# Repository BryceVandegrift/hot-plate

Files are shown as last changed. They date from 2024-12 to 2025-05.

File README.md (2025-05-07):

# PCB Hot Plate

A modular PCB soldering hot plate using only through hole components

## About

A modular PCB hot plate designed for hot plate soldering. It is designed for SMD
soldering and can go up to 180°C. Made using only through hole components in
order to make it easy to be built by hobbyists.

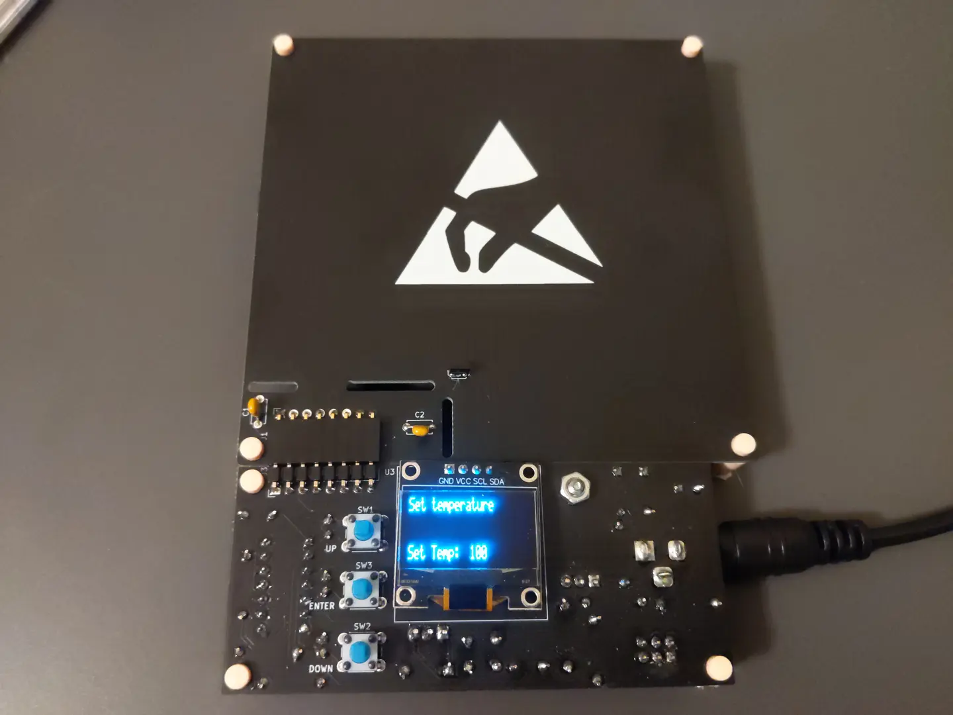
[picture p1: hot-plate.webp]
PCB Hot Plate


## Specifications

- 180°C max temperature
- Microcontroller: Atmel ATTINY84A
- Display: 128x64 pixel SSD1306 or compatible display
- Modular/interchangeable hot plates
- Support for simple heat curves
- 18-20 volt 2x5.5mm DC input
- 3 button input

Best used with low melt solder paste. This includes (but is not limited to):
- Sn48/In52
- Sn42/Bi58
- Sn42/Bi57/Ag1.0

## Usage

When you power up the hot plate you will be presented with 2 modes:

- Normal heating
- Heat curve

### Normal Heating

Normal heating mode is very simple to use. Just set a temperature and the hot
plate will heat up and stay at the set temperature. You can press `Enter` in
order to enter into cooling mode afterwards.

### Heat Curve

Heat curve mode lets you set and use your own custom heat curve. There are 5
parts to heat curve mode:

- Preheat: Temperature to preheat
- Soak: Amount of time (in seconds) to "soak" in preheat temperature
- Reflow heating: Temperature to reflow
- Reflow: Amount of time (in seconds) to reflow
- Cooldown

Pressing `Enter` will skip to the next stage of the heat curve.
Heat curve mode roughly follows this graph:

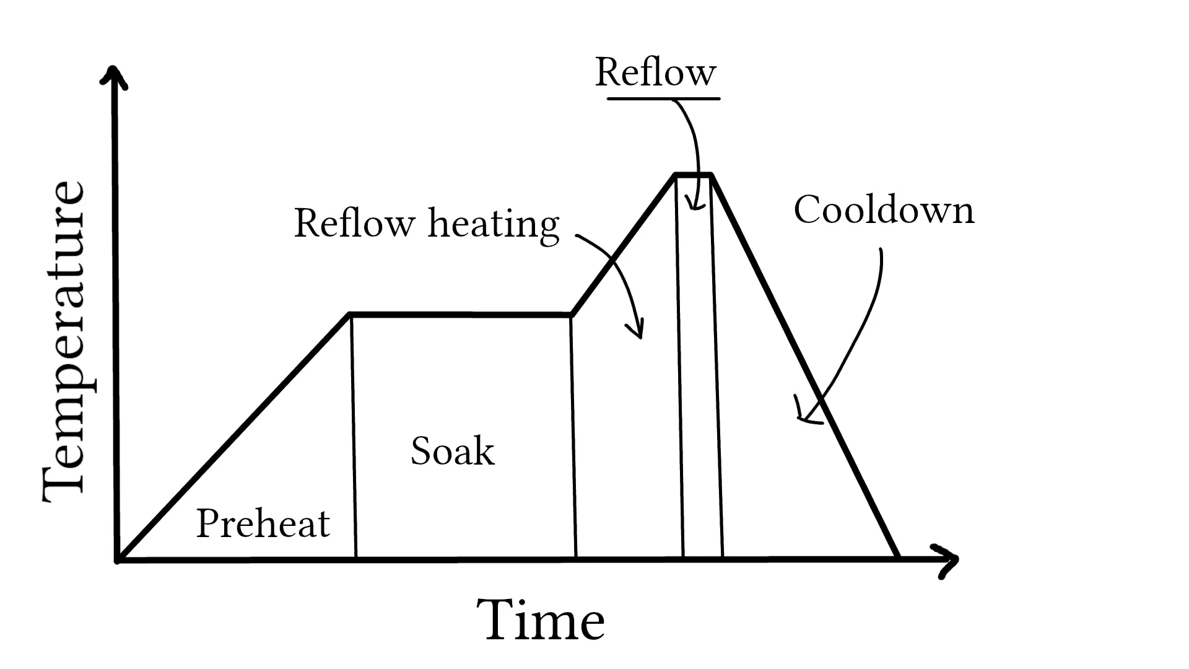
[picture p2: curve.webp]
Graph of heat curve


## Hardware

### Schematics

[Control Board Schematic](KiCAD/schematics/plate.pdf)

[Hot Plate Schematic](KiCAD/schematics/100x100-plate.pdf)

### Build Instructions

Please refer to the [Building Instructions](Build.md) page for detailed instructions.

### Connectors and Switches

#### J1 - DC Power Input

| Pin | Description |
| --- | --- |
| 1 | +18-20V power |
| 2 | Ground |
| 3 | Ground |

#### J2 - ISCP Header

| Pin | Description  |
| --- | ---  |
| 1 | MISO |
| 2 | +5V |
| 3 | SCL |
| 4 | MOSI |
| 5 | Reset |
| 6 | Ground |

#### J3 - Hot Plate Connector

| Pin | Description |
| --- | --- |
| 1 | NC |
| 2 | +18-20V |
| 3 | +18-20V |
| 4 | MOSFET drain |
| 5 | MOSFET drain |
| 6 | +5V |
| 7 | Ground |
| 8 | Temp. sensor output |

*Note: The J3 connector on the control board is exactly the same as the J1
connector on the hot plate board*

### Bill of Materials

A list of all Digikey parts can be found [here](https://www.digikey.com/en/mylists/list/93WA87OA5L)

#### Control Board

| Type | Reference | Description | Quantity | Source |
| ---- | --- | --- | --- | --- |
| Integrated Circuit | U1 | L7805CV voltage regulator | 1 | Digikey 497-1443-5-ND |
| Integrated Circuit | U2 | ATTINY84A-PU microcontroller | 1 | Digikey ATTINY84A-PU-ND |
| Display | U3 | SSD1306 128x64 0.96" display | 1 | Ebay, AliExpress, and other sources |
| IC Socket | U2 | DIP-14 300 mil socket | 1 | Digikey ED3014-ND |
| Diode | D1, D2 | SD103A | 2 | Digikey SD103AVSCT-ND |
| Diode | D3 | 1N5231 | 1 | Digikey 1N5231B-ND |
| MOSFET | Q1 | IRLZ44N | 1 | Digikey IRLZ44NPBF-ND |
| Capacitor | C1 | 100uF, Electrolytic, 3.5mm lead spacing | 1 | Digikey 732-9187-1-ND |
| Capacitor | C2-C4, C8 | 0.1uF, MLCC, 5mm lead spacing | 4 | Digikey BC2665CT-ND |
| Capacitor | C5-C7 | 3300pF, MLCC, 2.5mm lead spacing | 3 | Digikey BC1075CT-ND |
| Resistor | R1-R5, R7 | 10kOhm, through hole | 6 | Digikey 13-MFR-25FRF52-10KCT-ND |
| Resistor | R6 | 30kOhm, through hole | 1 | Digikey 13-MFR-25FTE52-30KCT-ND |
| Resistor | R8 | 200Ohm, throught hole | 1 | Digikey 200XBK-ND |
| Tactile Button | SW1-SW3 | 6mm tactile button | 3 | Digikey 450-1654-ND |
| DC Jack | J1 | 2x5.5mm, through hole, right angle | 1 | Digikey CP-002AH-ND |
| Pin Header | J2 | 6 pin header, 2.54mm pitch, 2x3 pins | 1 | Digikey 732-5394-ND |
| Pin Header | J3 | 8 pin header, 2.54mm pitch, right angle | 1 | Digikey 2057-PH1RB-08-UA-ND |

#### Hot Plate

| Type | Reference | Description | Quantity | Source |
| ---- | --- | --- | --- | --- |
| Integrated Circuit | U1 | LMT87LPGM temperature sensor | 1 | Digikey 296-LMT87LPGMCT-ND |
| Capacitor | C1, C2 | 0.1uF, MLCC, 5mm lead spacing | 2 | Digikey BC2665CT-ND |
| Pin Socket | J1 | 8 pin header, 2.54mm pitch, right angle | 1 | Digikey S5483-ND |

## License

Source code is licensed under the GPLV3 or later.

Everything else is licensed under the CERN-OHL-W-2.0.

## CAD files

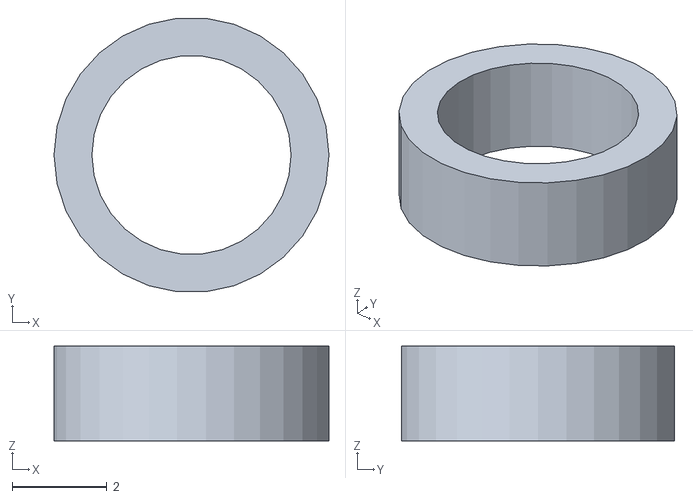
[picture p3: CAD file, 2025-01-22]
3d/ring.stl
5.80 x 5.77 x 2.00

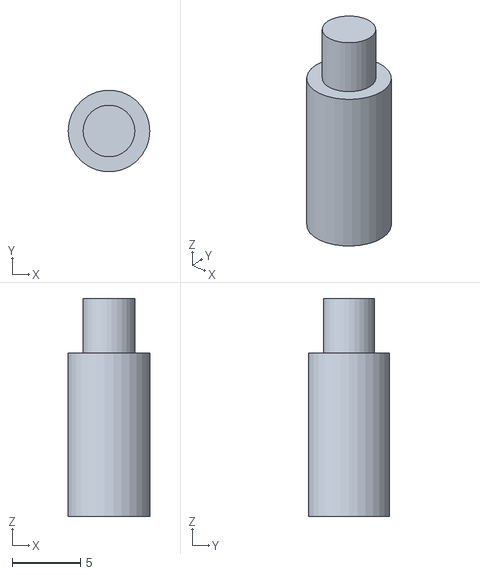
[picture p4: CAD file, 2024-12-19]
3d/peg.stl
6.00 x 5.97 x 16.0

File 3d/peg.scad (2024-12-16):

/* See LICENSE for license details. */

$fn = 30;

cylinder(h = 12, d = 6);
translate([0, 0, 12]) {
    cylinder(h = 4, d = 3.8);
}

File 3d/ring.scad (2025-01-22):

$fn = 30;

difference() {
    cylinder(h = 2, d = 5.8);
    translate([0, 0, -0.5]) {
        cylinder(h = 3, d = 3.8 + 0.4);
    }
}

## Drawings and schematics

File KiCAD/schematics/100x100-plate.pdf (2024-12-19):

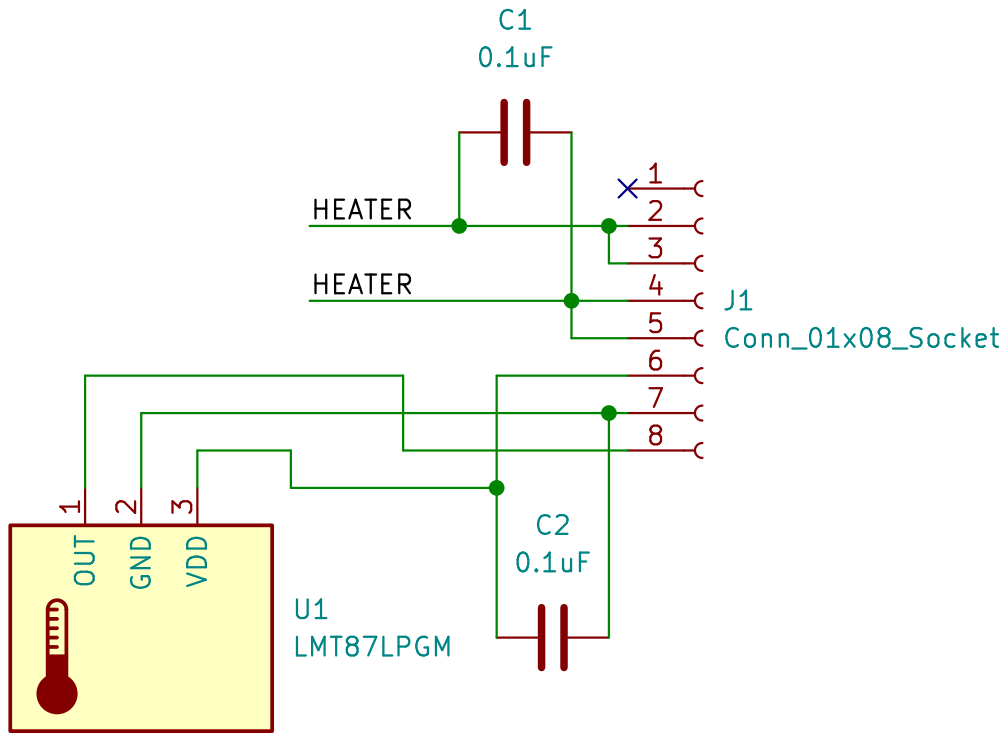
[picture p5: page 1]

Id: 1/1 Title: 100mm x 100mm PCB Hot Plate

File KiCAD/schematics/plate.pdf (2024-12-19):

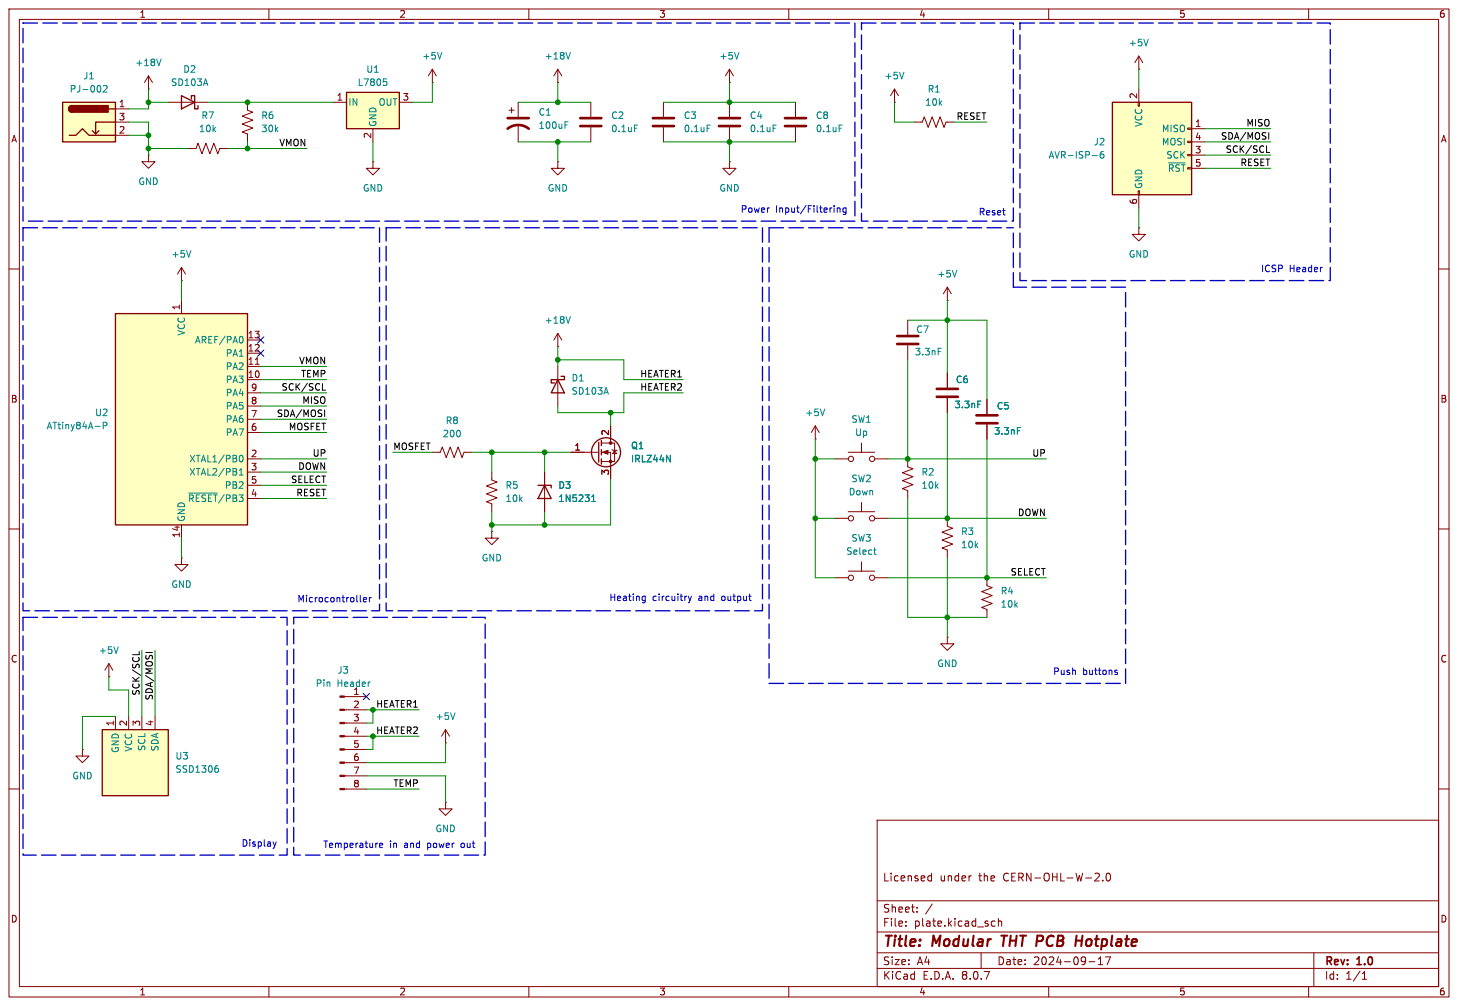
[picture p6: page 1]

2 SCK 3 MOSI 4 ~{RST}5 GND

SDA/MOSI UP MOSFET VMON
TEMP

Id: 1/1 Title: Modular THT PCB Hotplate

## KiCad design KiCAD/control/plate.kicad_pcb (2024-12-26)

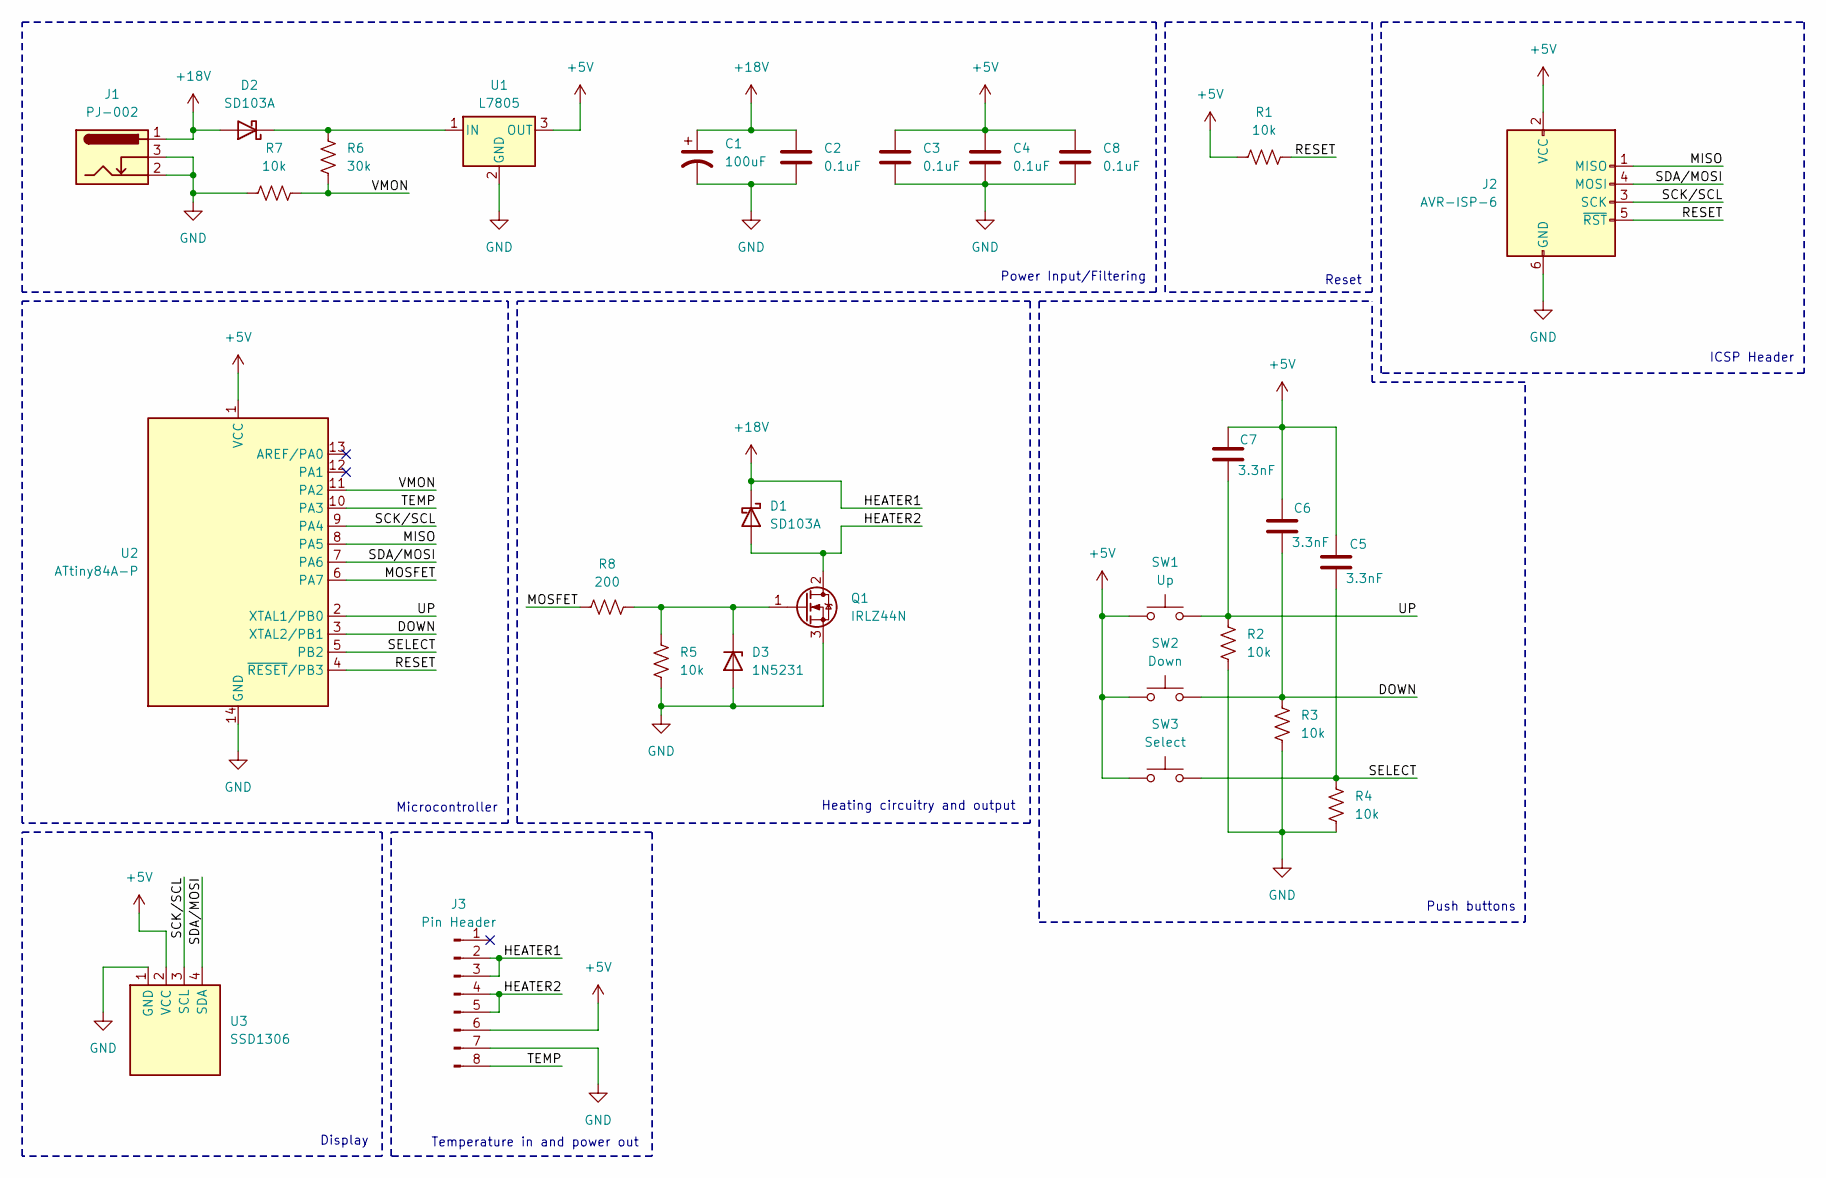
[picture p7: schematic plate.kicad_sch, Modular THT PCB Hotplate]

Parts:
C1: 100uF; CP_Radial_D8.0mm_P3.50mm
C2, C3, C4, C8: 0.1uF; C_Disc_D4.7mm_W2.5mm_P5.00mm
C5, C6, C7: 3.3nF; C_Disc_D3.8mm_W2.6mm_P2.50mm
D1, D2: SD103A; D_DO-35_SOD27_P7.62mm_Horizontal
D3: 1N5231; D_DO-35_SOD27_P7.62mm_Horizontal
J1: PJ-002; BarrelJack_Horizontal
J2: AVR-ISP-6; IDC-Header_2x03_P2.54mm_Vertical
J3: Pin Header; PinHeader_1x08_P2.54mm_Horizontal
Q1: IRLZ44N; TO-220-3_Horizontal_TabDown
R1, R2, R3, R4, R5, R7: 10k; R_Axial_DIN0207_L6.3mm_D2.5mm_P10.16mm_Horizontal
R6: 30k; R_Axial_DIN0207_L6.3mm_D2.5mm_P10.16mm_Horizontal
R8: 200; R_Axial_DIN0207_L6.3mm_D2.5mm_P10.16mm_Horizontal
SW1: Up; SW_PUSH_6mm_H7.3mm
SW2: Down; SW_PUSH_6mm_H7.3mm
SW3: Select; SW_PUSH_6mm_H7.3mm
U1: L7805; TO-220-3_Horizontal_TabDown
U2: ATtiny84A-P; DIP-14_W7.62mm_Socket
U3: SSD1306

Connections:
+5V: C3.1, C4.1, C5.1, C6.1, C7.1, C8.1, J2.2 (VCC), J3.6, R1.1, SW1.1, SW2.1, SW3.1, U1.3 (OUT), U2.1 (VCC), U3.2 (VCC)
+18V: C1.1, C2.1, D1.1 (K), D2.2 (A), J1.1, J3.2, J3.3
/DOWN: C6.2, R3.2, SW2.2, U2.3 (XTAL2/PB1)
/HEATER2: D1.2 (A), J3.4, J3.5, Q1.2 (D)
/MISO: J2.1 (MISO), U2.8 (PA5)
/MOSFET: R8.1, U2.6 (PA7)
/RESET: J2.5 (~RST), R1.2, U2.4 (~RESET/PB3)
/SCK/SCL: J2.3 (SCK), U2.9 (PA4), U3.3 (SCL)
/SDA/MOSI: J2.4 (MOSI), U2.7 (PA6), U3.4 (SDA)
/SELECT: C5.2, R4.2, SW3.2, U2.5 (PB2)
/TEMP: J3.8, U2.10 (PA3)
/UP: C7.2, R2.2, SW1.2, U2.2 (XTAL1/PB0)
/VMON: R6.1, R7.2, U2.11 (PA2)
GND: C1.2, C2.2, C3.2, C4.2, C8.2, D3.2 (A), J1.2, J1.3, J2.6 (GND), J3.7, Q1.3 (S), R2.1, R3.1, R4.1, R5.1, R7.1, U1.2 (GND), U2.14 (GND), U3.1 (GND)
unnamed: D2.1 (K), R6.2, U1.1 (IN)
unnamed: D3.1 (K), Q1.1 (G), R5.2, R8.2

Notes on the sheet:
Display
Heating circuitry and output
Push buttons
Power Input/Filtering
Temperature in and power out
Reset
ICSP Header
Microcontroller

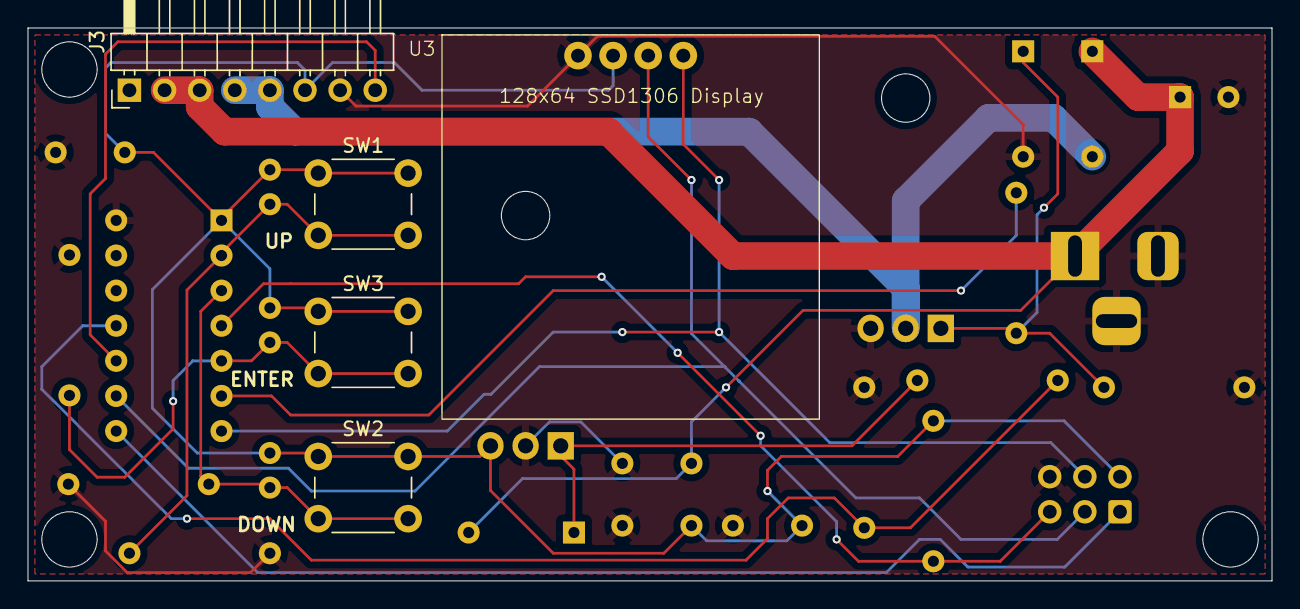
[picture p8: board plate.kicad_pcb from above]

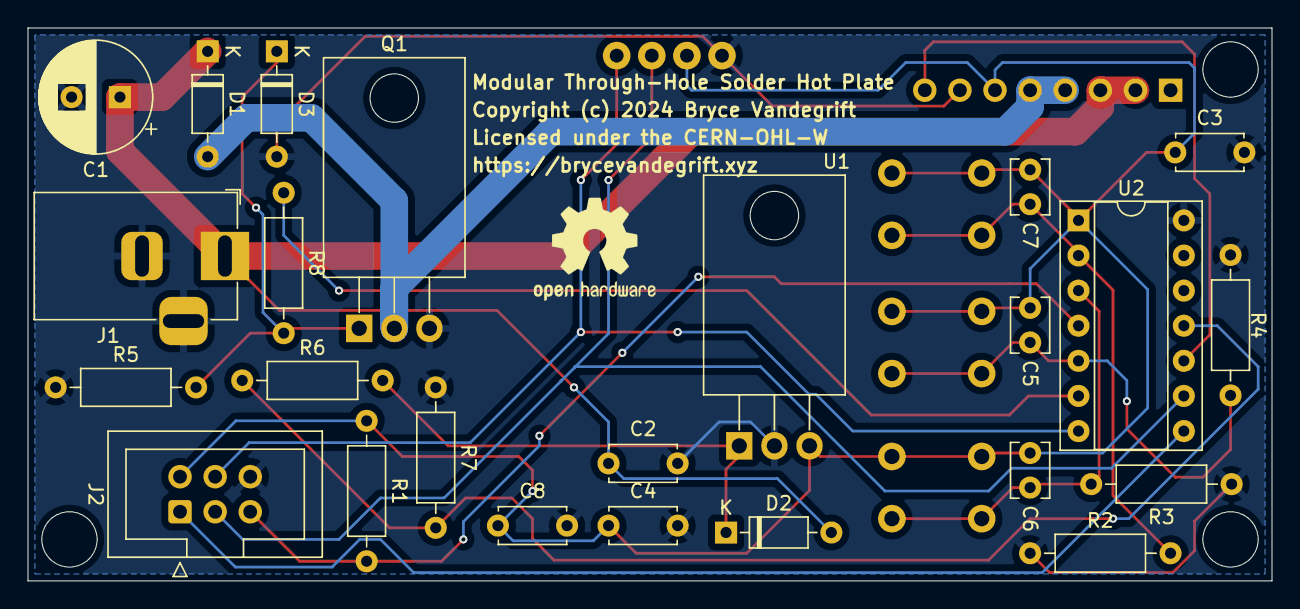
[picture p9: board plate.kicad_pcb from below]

Board: 2 copper layers, 90.0 x 40.0 mm, 29 parts (24 on the bottom side), 16 nets.

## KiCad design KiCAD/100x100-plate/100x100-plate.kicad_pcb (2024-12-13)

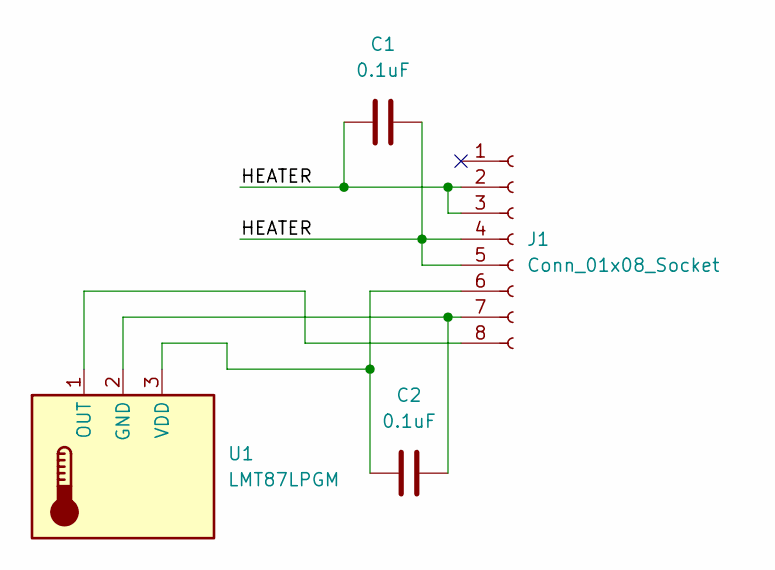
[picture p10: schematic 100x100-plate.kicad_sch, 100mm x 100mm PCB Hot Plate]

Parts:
C1, C2: 0.1uF; C_Disc_D4.7mm_W2.5mm_P5.00mm
J1: Conn_01x08_Socket; PinSocket_1x08_P2.54mm_Horizontal
U1: LMT87LPGM; TO-92Flat

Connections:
/HEATER: C1.1, C1.2, J1.2, J1.3, J1.4, J1.5
unnamed: C2.2, J1.6, U1.3 (VDD)
unnamed: C2.1, J1.7, U1.2 (GND)
unnamed: J1.8, U1.1 (OUT)

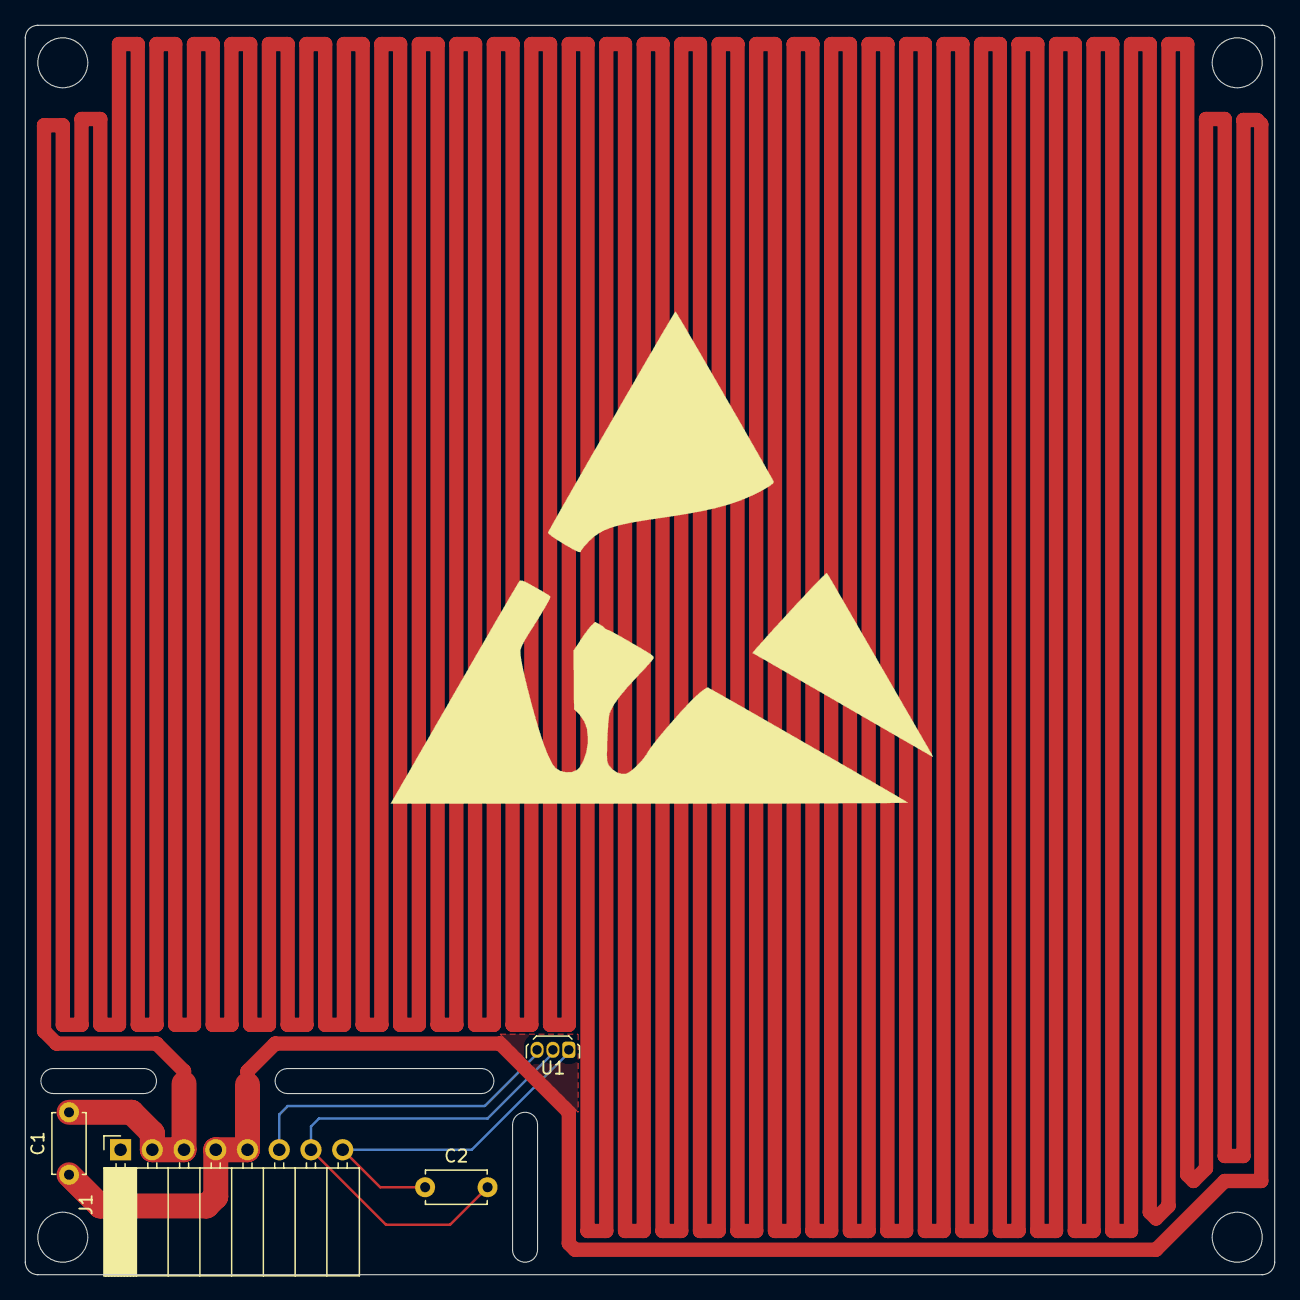
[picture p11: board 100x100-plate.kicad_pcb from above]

Board: 2 copper layers, 100.0 x 100.0 mm, 4 parts (0 on the bottom side), 4 nets.

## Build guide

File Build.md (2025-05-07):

# Building Instructions

## Prerequisites

### Tools and Equipment

- Soldering iron with a fine tip. Temperature controlled soldering station is
  recommended.
- Small side cutters for cutting components' leads.
- Desk lamp and or magnifying glass
- An ICSP programmer for programming the microcontroller
- Solder suitable for soldering electronics.
- Solder wick for removing excess solder.
- 90-99% Isopropyl Alcohol for removing the excess flux after soldering.
- Lint free wipes, used toothbrush, or cotton swabs for cleaning the PCB
  before and after soldering.
- A multimeter can be beneficial for troubleshooting.

### Parts

#### Getting Parts

A list of parts can be found in the [bill of materials](README.md#bill-of-materials) section
of the README.md file. You can find the provided parts from Digikey
(recommended), Mouser, or from any other electronics parts suppliers.

You can order PCBs using any PCB manufacturing service. I recommend using JLCPCB
since they will manufacture the PCBs for cheap. Just give them the
[gerber files](gerber) and make sure that you get a **Lead free** PCB (to be
safe).

#### Optional Parts

The ICSP header (J2) on the control board is optional if you get your ATTINY84A
pre-programmed or you use another method to program it besides ICSP.

#### 3D Printed Parts

This design also uses 3D printed legs and rings to hold everything up. If you don't have a
3D printer then you can use a 3D printing service like JLC3DP. You can use
almost any material for the legs, but I would recommend just normal PLA plastic.
You can find the STL files for the legs [here](3d/peg.stl) and the rings [here](3d/ring.stl).
I recommend printing with 0.1mm layer height at 100% infill.
Also don't worry, the legs and rings will **not** melt or majorly deform despite the heat.

#### Firmware

In order to flash the firmware to the ATTINY84A you can either use a pre-built
HEX file [here](src/main.hex) or build the firmware from scratch using the instructions
below.

## Building

### Build Steps

1. Inspect the PCB for obvious defects, such as deep scratches or short-circuits
   between traces.
2. Clean the PCB with an alcohol wipe.
3. Solder the components, going from lower profile components to higher profile
   ones.
4. Carefully inspect all the solder joints. Re-solder if needed. Optionally use
   a multimeter to check the board for short-circuits.
5. Clean the board using cotton swaps, wipes, and the toothbrush soaked in alcohol.
6. Insert the ATTINY84A into the socket and flash it using an ICSP programmer.
7. Attach the 3D printed feet to the boards, secure with rings, and connect the boards together.
8. Connect the power supply and if everything works you should see text on the
   screen.

### Flashing the Firmware

In order to flash the firmware using ICSP you'll need an ICSP programmer and the
`avrdude` software. Once you have the ICSP programmer hooked up to the board
(if you need help reference the schematic and board design), you'll need to run
this command to flash the firmware:

``` sh
avrdude -p t84a -P <port> -c <Your programmer> -b <baud rate> -U flash:w:main.hex
```

Where `<port>` is the port that your programmer is plugged into,
`<Your programmer>` is the type of ICSP programmer that you are using, and
`<baud rate>` is your desired baud rate.

### Building the Firmware

In order to build firmware for the hot plate you'll need to make sure you have
the AVR-GCC toolchain. This is easy to install for Linux using your package
manager and MacOS using homebrew. Windows users can use
[WinAVR](https://winavr.sourceforge.net/) to get the AVR toolchain on their
system. Besides GCC-AVR, you will need Make as well.

In order to build, go to the `src` directory and run:

``` sh
make
```

This will build the firmware and create a `main.hex` file which is what you need
to flash.

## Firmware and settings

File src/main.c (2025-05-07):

/* See LICENSE for license details. */

#include <avr/eeprom.h>
#include <avr/io.h>
#include <util/delay.h>

#include "oled.h"

#define DEBOUNCE while((PINB & (1 << PINB0)) || (PINB & (1 << PINB1)) || (PINB & (1 << PINB2))) {}

#define MOSFET_ON PORTA |= (1 << PORTA7)
#define MOSFET_OFF PORTA &= ~(1 << PORTA7)

#define TEMP_ADDR 0x00
#define PREHEAT_ADDR 0x01
#define REFLOW_ADDR 0x02
#define SOAK_ADDR 0x03
#define LIQUID_ADDR 0x04

/* min and max temperatures */
#define MAX_TEMP 180
#define MIN_TEMP 50

/* min and max times for soak and reflow */
#define MAX_SOAK 250
#define MIN_SOAK 10
#define MAX_REFLOW 60
#define MIN_REFLOW 1
/* 2000 mV on ADC is around 6.5 V */
#define MIN_MV 2000

#define VERSION "Version 2.0"

static void setup(void);
static uint8_t analog_read(uint8_t pin);
static void int_to_str(char *s, uint16_t n);
static uint16_t read_temp(void);
static uint16_t read_volts(void);
static void cool(void);
static void heat(const char *msg, uint8_t set_temp, uint8_t stop);
static void hold(const char *msg, uint8_t set_temp, uint8_t set_sec);
static void set_var(const char *msg1, const char *msg2, uint8_t min, uint8_t max, uint8_t *var);
static void normal_mode(void);
static void curve_mode(void);

/* normal mode temperature */
static uint8_t temp = MIN_TEMP;
/* curve mode temperatures */
static uint8_t preheat = MIN_TEMP;
static uint8_t reflow = 100;
/* curve mode times */
static uint8_t soak = 30;
static uint8_t liquid = 10;

void
setup()
{
	uint8_t eeprom;

	/* Pinouts:
	 * PA0: Not connected
	 * PA1: Not connected
	 * PA2: Voltage monitor
	 * PA3: Temperature input
	 * PA4: Slave clock
	 * PA5: Not used (MISO)
	 * PA6: Slave data
	 * PA7: MOSFET output
	 *
	 * PB0: UP button input
	 * PB1: DOWN button input
	 * PB2: SELECT button input
	 * PB3: Not used (RESET)
	 */
	DDRA = 0xd0; /* 11010000 */
	DDRB = 0x00;

	PORTA = 0x50; /* 01010000 */
	PORTB = 0x00;

	/* enable power to ADC */
	PRR &= ~(1 << PRADC);

	/* use VCC as AREF */
	ADMUX &= ~((1 << REFS1) | (1 << REFS0));

	/* left justify ADC bits for clean 8-bit value */
	ADCSRB |= (1 << ADLAR);

	/* enable ADC on port A */
	ADCSRA |= (1 << ADEN);

	/* pull normal mode temp from eeprom */
	__EEGET(eeprom, TEMP_ADDR);
	if (eeprom >= MIN_TEMP && eeprom <= MAX_TEMP) {
		temp = eeprom;
	}

	/* pull heat curve mode variables */
	eeprom_busy_wait();
	__EEGET(eeprom, PREHEAT_ADDR);
	if (eeprom >= MIN_TEMP && eeprom <= MAX_TEMP) {
		preheat = eeprom;
	}

	eeprom_busy_wait();
	__EEGET(eeprom, REFLOW_ADDR);
	if (eeprom >= MIN_TEMP && eeprom <= MAX_TEMP) {
		reflow = eeprom;
	}

	eeprom_busy_wait();
	__EEGET(eeprom, SOAK_ADDR);
	if (eeprom >= MIN_SOAK && eeprom <= MAX_SOAK) {
		soak = eeprom;
	}

	eeprom_busy_wait();
	__EEGET(eeprom, LIQUID_ADDR);
	if (eeprom >= MIN_REFLOW && eeprom <= MAX_REFLOW) {
		liquid = eeprom;
	}
}

uint8_t
analog_read(uint8_t pin)
{
	ADMUX = ((ADMUX & 0xf0) | pin);

	ADCSRA |= (1 << ADSC);
	while (ADCSRA & (1 << ADSC));
	return ADCH;
}

void
int_to_str(char *s, uint16_t n)
{
	uint16_t i = 10000;
 
	while (i > n) i /= 10;

	do {
		*s++ = '0' + (((n - n % i) / i) % 10);
	} while (i /= 10);

	if (n < 100) {
		*s = ' ';
		s++;
	}

	*s = 0;
}

uint16_t
read_temp()
{
	uint8_t i;
	float data = 0;

	for (i = 0; i < 100; i++) {
		data += analog_read(PINA3);
	}

	data /= 100;
	data *= 19.53125; /* (5.0 / 256) * 1000 */
	return (uint16_t)((data - 2637) / -13.6);
}

uint16_t
read_volts()
{
	uint8_t i;
	float data = 0;

	for (i = 0; i < 20; i++) {
		data += analog_read(PINA2);
	}

	data /= 20;
	data *= 19.53125; /* (5.0 / 256) * 1000 */
	return (uint16_t)data;
}

void
cool()
{
	uint16_t rtemp;
	char buf[8];

	oled_clear();

	DEBOUNCE;

	oled_setpos(0, 0);
	oled_print("Cooling...");

	oled_setpos(0, 3);
	oled_print("Temp: ");

	for (;;) {
		oled_setpos(32, 3);
		rtemp = read_temp();
		int_to_str(buf, rtemp);
		oled_print(buf);

		if (PINB & (1 << PINB2)) {
			break;
		}

		_delay_ms(10);
	}
}

void
heat(const char *msg, uint8_t set_temp, uint8_t stop)
{
	uint16_t rtemp;
	char buf[8];

	oled_clear();

	DEBOUNCE;

	oled_setpos(0, 0);
	oled_print(msg);

	oled_setpos(0, 3);
	oled_print("Temp: ");

	for (;;) {
		oled_setpos(32, 3);
		rtemp = read_temp();
		int_to_str(buf, rtemp);
		oled_print(buf);

		if (read_volts() < MIN_MV) {
			goto undervolt;
		}

		if (rtemp < set_temp) {
			MOSFET_ON;
		} else {
			MOSFET_OFF;
		}

		if (PINB & (1 << PINB2)) {
			break;
		}

		/* if stop is set and target temp is reached, return */
		if (stop && rtemp >= set_temp) {
			return;
		}

		_delay_ms(10);
	}

	MOSFET_OFF;

	return;

undervolt:

	MOSFET_OFF;

	oled_clear();
	oled_setpos(0, 0);
	oled_print("Voltage is too low!");

	for (;;) {
		if (PINB & (1 << PINB2)) {
			break;
		}
	}
}

void
hold(const char *msg, uint8_t set_temp, uint8_t set_sec)
{
	uint16_t rtemp;
	char buf[8];
	uint8_t i;

	oled_clear();

	DEBOUNCE;

	oled_setpos(0, 0);
	oled_print(msg);

	oled_setpos(0, 2);
	oled_print("Time: ");

	oled_setpos(0, 3);
	oled_print("Temp: ");

	/*
	 * a simple (but inaccurate) alternative to using timers.
	 * works well enough I guess... 
	 */
	for (i = set_sec; i > 0; i--) {
		oled_setpos(32, 3);
		rtemp = read_temp();
		int_to_str(buf, rtemp);
		oled_print(buf);

		oled_setpos(32, 2);
		int_to_str(buf, i);
		oled_print(buf);

		if (read_volts() < MIN_MV) {
			goto undervolt;
		}

		if (rtemp < set_temp) {
			MOSFET_ON;
		} else {
			MOSFET_OFF;
		}

		if (PINB & (1 << PINB2)) {
			break;
		}

		_delay_ms(1000);
	}

	MOSFET_OFF;

	return;

undervolt:

	MOSFET_OFF;

	oled_clear();
	oled_setpos(0, 0);
	oled_print("Voltage is too low!");

	for (;;) {
		if (PINB & (1 << PINB2)) {
			break;
		}
	}
}

void
set_var(const char *msg1, const char *msg2, uint8_t min, uint8_t max, uint8_t *var)
{
	char buf[8];

	oled_clear();

	oled_setpos(0, 0);
	oled_print(msg1);

	oled_setpos(0, 3);
	oled_print(msg2);

	for (;;) {
		oled_setpos(64, 3);
		int_to_str(buf, *var);
		oled_print(buf);

		if (PINB & (1 << PINB0) && *var < max) {
			(*var)++;
		} else if (PINB & (1 << PINB1) && *var > min) {
			(*var)--;
		} else if (PINB & (1 << PINB2)) {
			return;
		}

		_delay_ms(100);
	}
}

void
normal_mode()
{
	oled_clear();

	DEBOUNCE;

	set_var("Set temperature", "Set temp:", MIN_TEMP, MAX_TEMP, &temp);

	/* write normal mode temp to eeprom */
	__EEPUT(TEMP_ADDR, temp);

	heat("Heating...", temp, 0);
	cool();
}

void
curve_mode()
{
	oled_clear();

	DEBOUNCE;

	set_var("Set preheat temp", "Set temp:", MIN_TEMP, MAX_TEMP, &preheat);
	set_var("Set soak time", "Set time:", MIN_SOAK, MAX_SOAK, &soak);
	set_var("Set reflow temp", "Set temp:", MIN_TEMP, MAX_TEMP, &reflow);
	set_var("Set reflow time", "Set time:", MIN_REFLOW, MAX_REFLOW, &liquid);

	/* write heat curve values to eeprom */
	__EEPUT(PREHEAT_ADDR, preheat);
	eeprom_busy_wait();
	__EEPUT(SOAK_ADDR, soak);
	eeprom_busy_wait();
	__EEPUT(REFLOW_ADDR, reflow);
	eeprom_busy_wait();
	__EEPUT(LIQUID_ADDR, liquid);

	heat("Preheating...", preheat, 1);
	hold("Soaking...", preheat, soak);
	heat("Heating to reflow...", reflow, 1);
	hold("Reflowing...", reflow, liquid);
	cool();
}

int
main()
{
	uint8_t cursor = 0;

	setup();

	_delay_ms(1000);

	oled_init();
	oled_clear();
	oled_setpos(0, 0);
	oled_print("PCB Hot Plate");
	oled_setpos(0, 3);
	oled_print(VERSION);
	_delay_ms(3000);

reset:
	oled_clear();

	oled_setpos(0, 0);
	oled_print("Select mode:");

	oled_setpos(8, 2);
	oled_print("Normal heating");

	oled_setpos(8, 3);
	oled_print("Heat curve");

	for (;;) {
		if (!cursor) {
			oled_setpos(0, 2);
			oled_print(">");
			oled_setpos(0, 3);
			oled_print(" ");
		} else {
			oled_setpos(0, 2);
			oled_print(" ");
			oled_setpos(0, 3);
			oled_print(">");
		}

		if (PINB & (1 << PINB0) || PINB & (1 << PINB1)) {
			cursor = !cursor;
		} else if (PINB & (1 << PINB2)) {
			if (cursor) {
				curve_mode();
			} else {
				normal_mode();
			}

			break;
		}

		_delay_ms(100);
	}

	goto reset;

	return 0;
}

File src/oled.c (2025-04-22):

/* See LICENSE for license details. */

#include <avr/io.h>
#include <avr/pgmspace.h>

#include "font.h"
#include "oled.h"

#define SDA_ON PORTA |= (1 << PORTA6)
#define SDA_OFF PORTA &= ~(1 << PORTA6)
#define SCL_ON PORTA |= (1 << PORTA4)
#define SCL_OFF PORTA &= ~(1 << PORTA4)

#define READ_SDA PINA & (1 << PINA6)
#define READ_SCL PINA & (1 << PINA4)

#define OLED_ADDRESS 0x3c
#define OLED_COMMAND 0x00
#define OLED_DATA 0x40

static void i2c_tx(uint8_t data);
static void i2c_start(void);
static void i2c_stop(void);

/* init sequence for oled display */
static const uint8_t init_bytes[] PROGMEM = {
	0xae,
	0xd5,
	0x80,
	0xa8,
	0x1f,
	0xd3,
	0x00,
	0x40,
	0x8d,
	0x14,
	0x20,
	0x00,
	0xa0,
	0xc8,
	0xda,
	0x02,
	0x81,
	0x8f,
	0xd9,
	0xc2,
	0xdb,
	0x40,
	0xa4,
	0xa6,
	0x2e,
	0xa1,
	0xaf
};

void
i2c_tx(uint8_t data)
{
	uint8_t i;

	for (i = 0; i < 8; i++) {
		if (data & 0x80) {
			SDA_ON;
		} else {
			SDA_OFF;
		}

		SCL_ON;
		SCL_OFF;
		data <<= 1;
	}

	SDA_ON;
	SCL_ON;
	SCL_OFF;
}

void
i2c_start()
{
	SDA_ON;
	SCL_ON;
	SDA_OFF;
	SCL_OFF;

	i2c_tx(OLED_ADDRESS << 1);
}

void
i2c_stop()
{
	SDA_OFF;
	SCL_ON;
	SDA_ON;
}

void
oled_init()
{
	uint8_t i;

	i2c_start();
	/* send commands */
	i2c_tx(OLED_COMMAND);

	for (i = 0; i < sizeof(init_bytes); i++) {
		i2c_tx(pgm_read_byte(&init_bytes[i]));
	}

	i2c_stop();
}

void
oled_clear()
{
	uint8_t i, j;

	for (i = 0; i < 8; i++) {
		i2c_start();
		i2c_tx(OLED_COMMAND);
		
		i2c_tx(0xb0 + i);
		i2c_tx(0x00);
		i2c_tx(0x10);

		i2c_stop();

		i2c_start();
		i2c_tx(OLED_DATA);

		for (j = 0; j < 128; j++) {
			i2c_tx(0x00);
		}

		i2c_stop();
	}
}

void
oled_setpos(uint8_t x, uint8_t y)
{
	i2c_start();
	i2c_tx(OLED_COMMAND);

	i2c_tx(0xb0 + y);
	i2c_tx(((x & 0xf0) >> 4) | 0x10);
	i2c_tx((x & 0x0f) | 0x01);

	i2c_stop();
}

void
oled_putchar(char c)
{
	uint8_t i;

	c -= 32;

	i2c_start();
	i2c_tx(OLED_DATA);

	for (i = 0; i < 6; i++) {
		i2c_tx(pgm_read_byte(&font[c * 6 + i]));
	}

	i2c_stop();
}

void
oled_print(const char *s)
{
	while (*s) {
		oled_putchar(*s++);
	}
}

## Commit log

2024-12-13 Add LICENSE
    Add CERN Open Hardware License Weakly reciprocal for PCB and 3D models
2024-12-16 Add README.md
    Add description of project, links, and BOM
2024-12-16 Add license information
    Add additional license information and add GPL V3 or later to source
    code
    [100x100-plate.kicad_sch, peg.scad, plate.kicad_sch]
2024-12-19 Add schematics, .stl file, and .hex file
    [peg.stl]
2024-12-26 Change references to screen resolution
    Change screen resolution from 128x32 to 128x64.
    Turns out screen resolution is *not* 128x32...oops.
    [plate.kicad_pcb]
2025-01-22 Add 3D printed rings to help secure legs
    [ring.scad, ring.stl]
2025-04-22 Add .gitignore and add button debouncing
2025-05-07 Update board software to 2.0
    This version adds support for very simple heat curves in order to
    somewhat automate the soldering process.

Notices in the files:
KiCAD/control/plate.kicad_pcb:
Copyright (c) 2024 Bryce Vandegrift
